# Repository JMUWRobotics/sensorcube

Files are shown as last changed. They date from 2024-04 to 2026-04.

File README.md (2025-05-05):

# Sensor Cube
Documentation, design and example code for the Sensor Cube used for teaching at the Robotics Lab of the Julius Maximilian University of Würzburg.
* The sensors can be used without specialized drivers. The stereo camera behaves like a webcam. The Arduino offers a virtual serial port over USB with sensor messages in JSON format.
* Contact: Michael Bleier (michael.bleier@uni-wuerzburg.de)

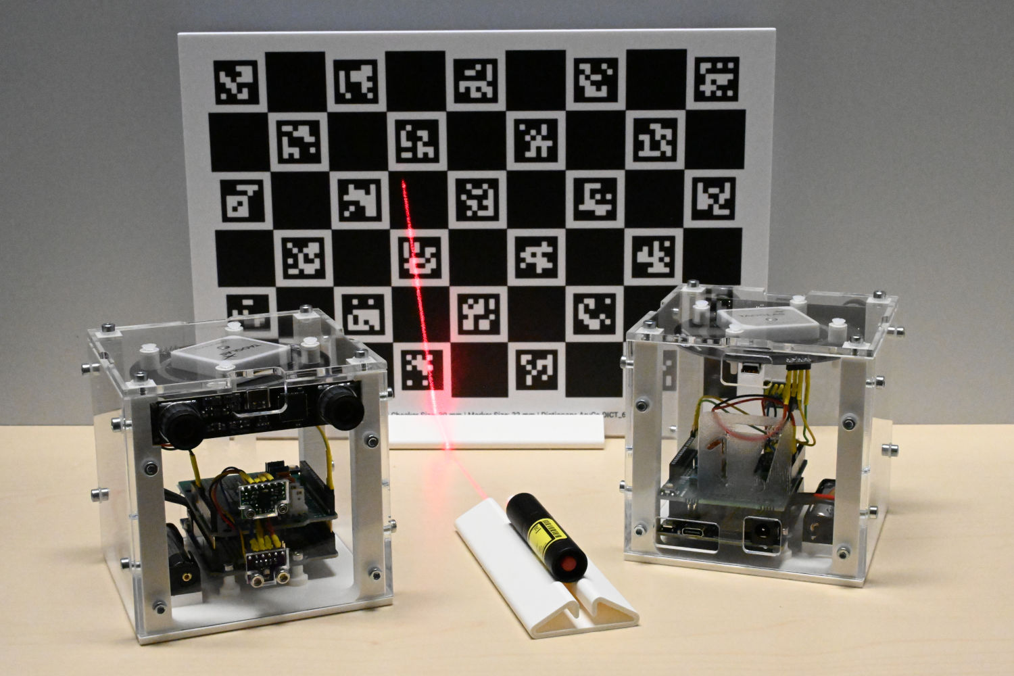
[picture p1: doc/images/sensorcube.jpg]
Image of Sensor Cube Sensor Cube


## Sensors and Kit
* Stereo camera module (https://www.elpcctv.com/elp-4mp-3840x1080p-60fps-synchronous-dual-lens-usb-camera-module-with-no-distortion-85-degree-lens-p-406.html)
* Arduino UNO R4 WiFi
  * U-blox NEO-M8T timing GNSS module (https://www.u-blox.com/en/product/neolea-m8t-series, https://gnss.store/neo-m8t-timing-gnss-modules/53-elt0040.html)
  * ST VL53L3CX Time-of-Flight multi-target distance sensor (https://www.st.com/en/imaging-and-photonics-solutions/vl53l3cx.html, https://www.pololu.com/product/3416)
  * Bosch BMP280 pressure and temperature sensor (https://www.bosch-sensortec.com/products/environmental-sensors/pressure-sensors/bmp280/, https://www.berrybase.de/bmp280-breakout-board-2in1-sensor-fuer-temperatur-und-luftdruck)
  * Bosch BNO055 Inertial Measurement Unit (https://www.bosch-sensortec.com/products/smart-sensor-systems/bno055/, https://docs.arduino.cc/hardware/9-axis-motion-shield/)
* Red Line Laser 650nm (https://www.laserfuchs.de/p/70134933)
* Calibration Board
* Folding Ruler

## Datasheets
* U-blox NEO-M8T timing GNSS module: https://www.u-blox.com/sites/default/files/documents/NEO-LEA-M8T-FW3_DataSheet_UBX-15025193.pdf
* ST VL53L3CX Time-of-Flight multi-target distance sensor: https://www.st.com/resource/en/datasheet/vl53l3cx.pdf
* Bosch BMP280 pressure and temperature sensor: https://www.bosch-sensortec.com/media/boschsensortec/downloads/datasheets/bst-bmp280-ds001.pdf
* Bosch BNO055 Inertial Measurement Unit: https://www.bosch-sensortec.com/media/boschsensortec/downloads/datasheets/bst-bno055-ds000.pdf

## Configuration
In the root directory is a configuration file _"config.json"_. Please make sure to set _"serial\_port"_ (typically _"/dev/ttyACM[0-9]"_ on Linux or _"COM[1-9]"_ on Windows) and the correct _"camera\_index"_ for the stereo camera.

```
"config.json":
  {
    "serial_port" : "/dev/ttyACM0",
    "serial_baudrate" : 921600,
    "camera_index" : 0,
    "camera_width" : 1600,
    "camera_height": 600
  }
```

The Python examples load this file relative to the _*.py_ source files. For the C++ examples CMake sets the path relative to the project source dir and bakes the path in the executables.

## Udev Rules Setup
On GNU/Linux make sure that you have access rights for the serial device (typically _"/dev/ttyACM[0-9]"_) of the Arduino in the Sensor Cube. On Debian/Ubuntu the device will have access rights for the group _plugdev_. Make sure your user is in the group _plugdev_.

Alternatively, the repository includes a udev rule, which grants read and write access to the device for all users:
```
sudo cp udev/99-sensorcube.rules /etc/udev/rules.d/
sudo udevadm control --reload-rules
```

## Using the Sensor Cube with Python
Set up your Python programming environment.

* Install Python3. On GNU/Linux you can use your favorite package manager to install Python, e.g., on Debian/Ubuntu install the package:
  ```
  sudo apt install python3
  ```
* On GNU/Linux use your favorite package manager to install the Python dependencies, e.g., on Debian/Ubuntu install the packages:
  ```
  sudo apt install python3-opencv python3-serial python3-matplotlib python3-numpy
  ```
  Or, use _pip_ to install the dependencies:
  ```
  $ pip install opencv-python pyserial matplotlib numpy
  ```
* Inspect the Python examples in the directory [_examples/python_](examples/python).

## Using the Sensor Cube with C++
Set up your C++ programming environment.

* Set up your C++ programming environment and compiler, e.g., _GCC_ on GNU/Linux or _Visual Studio/MSVC_ on Windows.
* Install the _OpenCV_ library.

  For image processing we will be using the _OpenCV_ library which is available	across platforms. It is recommended to use version 4.5.4. However, any version newer than 4.4.0 should be fine to complete the assignments.

  Please refer to: https://docs.opencv.org/4.5.4/df/d65/tutorial_table_of_content_introduction.html

  GNU/Linux: Use your favorite package manager to install OpenCV, e.g., on Debian/Ubuntu install the package:
  ```
  sudo apt install libopencv-dev
  ```
  Windows: You can download the _OpenCV_ binary release from https://opencv.org/releases/. You need to add the path to the unpacked directory _"opencv/build/x64/vc16/bin"_ to your System Path, such that the _OpenCV_ DLLs are found.
  
  Of course it is also possible to compile OpenCV yourself or use other ways for the installation as listed in the _OpenCV_ documentation.
* Install the _CMake_ build system.

  GNU/Linux: Use your favorite package manager to install _CMake_, e.g., on Debian/Ubuntu install the package:
  ```
  sudo apt install cmake
  ```
  Windows: You can download _CMake_ from https://cmake.org/download/.
  
* All other library dependencies (_Eigen3_, _Nlohmann JSON_, and _Asio_) are automatically downloaded by _CMake_. Inspect the _"examples/cpp/CMakeLists.txt"_ project file.
* Build the C++ examples. The recommended way of building a project with _CMake_ is by doing an out-of-source build. This can be done like this:
  ```
  $ cd examples/cpp
  $ mkdir build && cd build
  $ cmake ..
  $ make
  ```
  If _OpenCV_ is not installed in the standard paths, you might need to set the _OpenCV_ directory:
  ```
  $ cmake -DOpenCV_DIR=<Path to directory OpenCVConfig.cmake> ..
  ```
  If you are using the _OpenCV_ binary release on Windows, you need to specify the path to the unpacked directory _"opencv/build/x64/vc16/lib"_.

  Different _CMake_ Generators are available, such as _Unix Makefiles_ or _Ninja_. On Windows CMake can create, for example, _Visual Studio_ project files, _NMake_, or _Unix Makefiles_: https://cmake.org/cmake/help/latest/manual/cmake-generators.7.html
	
  For example, on Windows you can run from the Visual Studio developer command prompt:
  ```
  $ cmake -G "NMake Makefiles" ..
  $ nmake
  ```
* Inspect the C++ examples in the directory [_examples/cpp/src_](examples/cpp/src).

## Tools
* Record messages:
  ```
  python3 recordMessages.py -m <message_type> -f <file_name>
  ```
  Example record _imu_raw_ data to file _imu_raw.json_:
  ```
  python3 recordMessages.py -m imu_raw -f imu_raw.json
  ```
* Print messages:
  Without the file option _-f_ you can also use the record tool to print the messages.
  ```
  python3 recordMessages.py -m <message_type>
  ```
* Plot raw IMU data:
  ```
  python3 showIMU.py
  ```
* Capture Images:
  ```
  python3 captureCamera.py
  ```
  Press spacebar to capture images and ESC to quit.

* Update Real Time Clock:
  ```
  python3 setTime.py
  ```
## Known Issues
* The Arduino UNO R4 WiFi uses the internal oscillator instead of an external crystal as a clock source for the Real Time Clock (RTC). This causes significant time drift.
* The stereo camera can be slow with _OpenCV_ Video Capture. Therefore, the default configuration uses a stereo image size of only 1600 x 600.
* OpenCV changed the physical layout (the order of the 2D barcodes) of ChArUco boards in OpenCV 4.6.0. A fix was added in OpenCV 4.8.0 ("board.setLegacyPattern(True)"). Therefore, the ChArUco boards in the Sensor Cube boxes cannot be detected with OpenCV versions >= 4.6.0 and < 4.8.0.\
GitHub issue: https://github.com/opencv/opencv/issues/23152

## Publication
The following publication talks about some of the design aspects and application of the Sensor Cube for teaching: https://doi.org/10.1016/j.ifacol.2024.08.456
```
Bleier, M. (2024). Sensor Cube – A Tool for Hands-on Learning of Sensor Data Processing. IFAC-PapersOnLine, 58(16), 23-28.
```

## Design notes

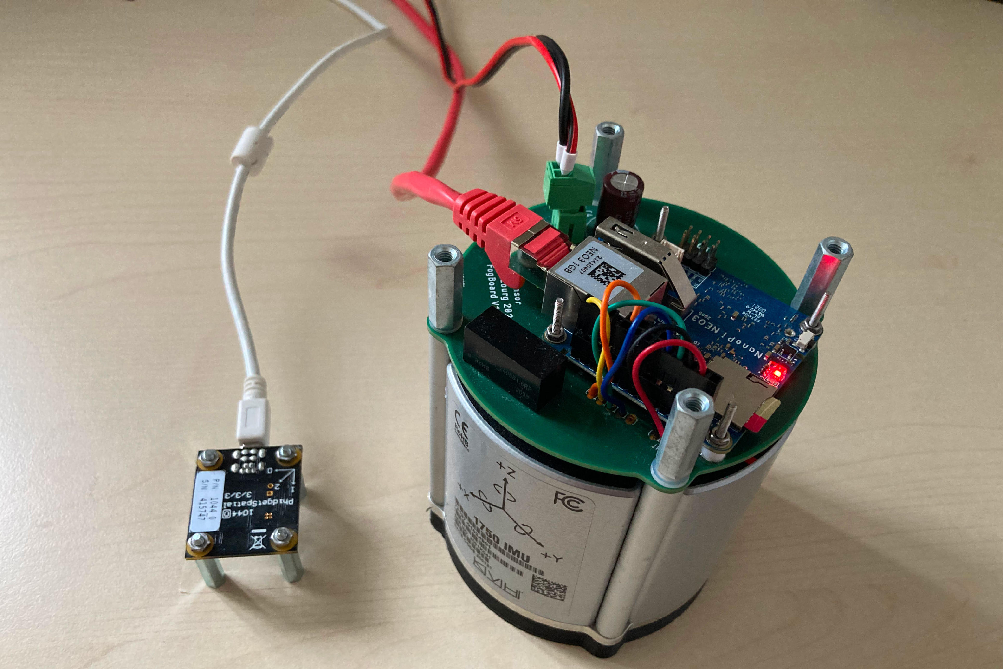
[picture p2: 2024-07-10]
doc/images/phidgets_spatial_kvh_fog.jpg

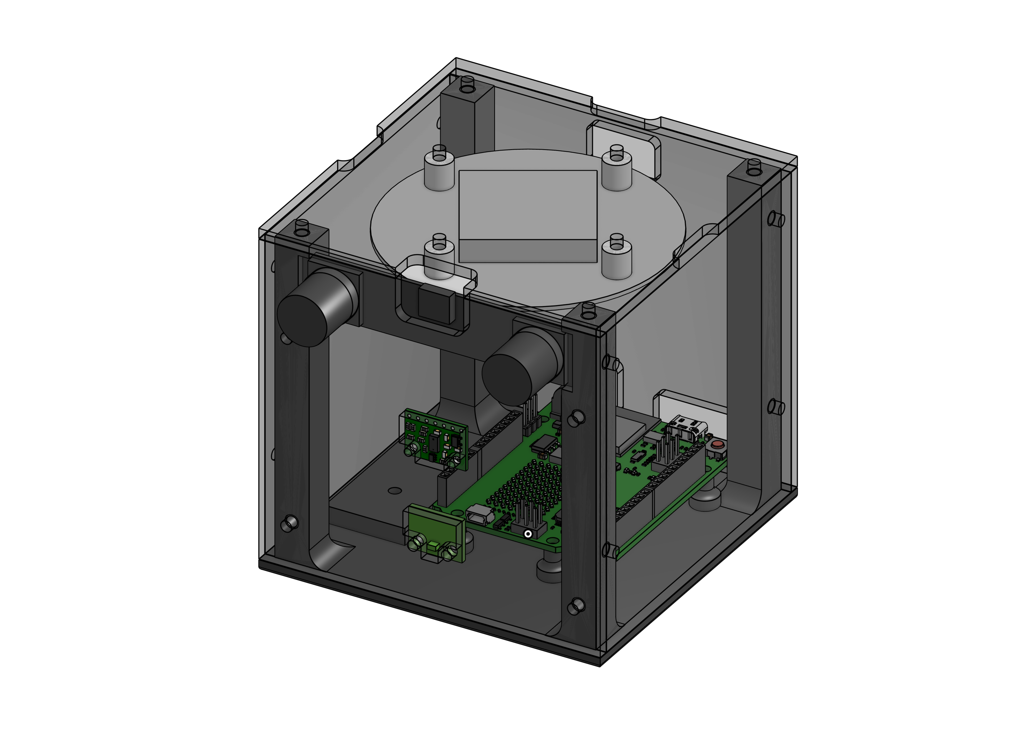
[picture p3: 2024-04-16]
cad/Cube002.png

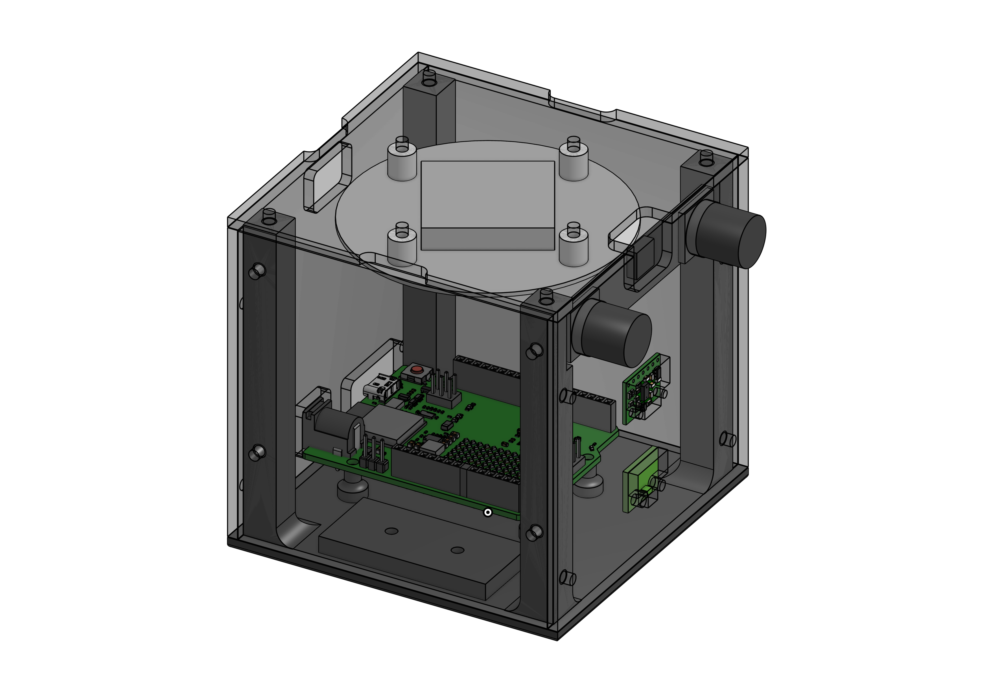
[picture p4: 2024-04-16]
cad/Cube001.png

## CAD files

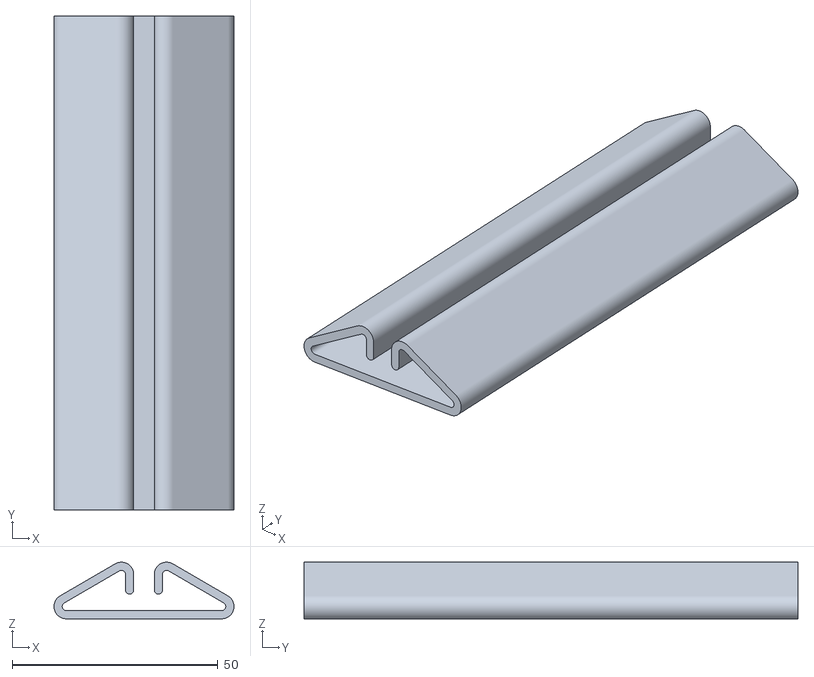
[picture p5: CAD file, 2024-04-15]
cad/3dprint/BoardStand.stl
43.8 x 120.0 x 13.8

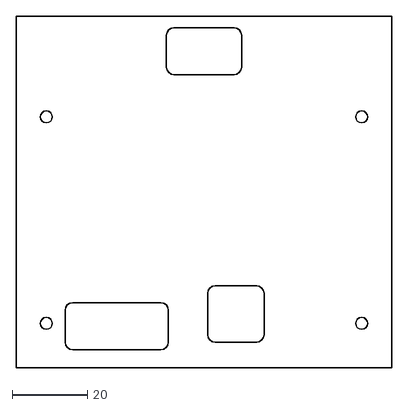
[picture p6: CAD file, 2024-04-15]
cad/lasercut/Front.dxf
100.0 x 93.6

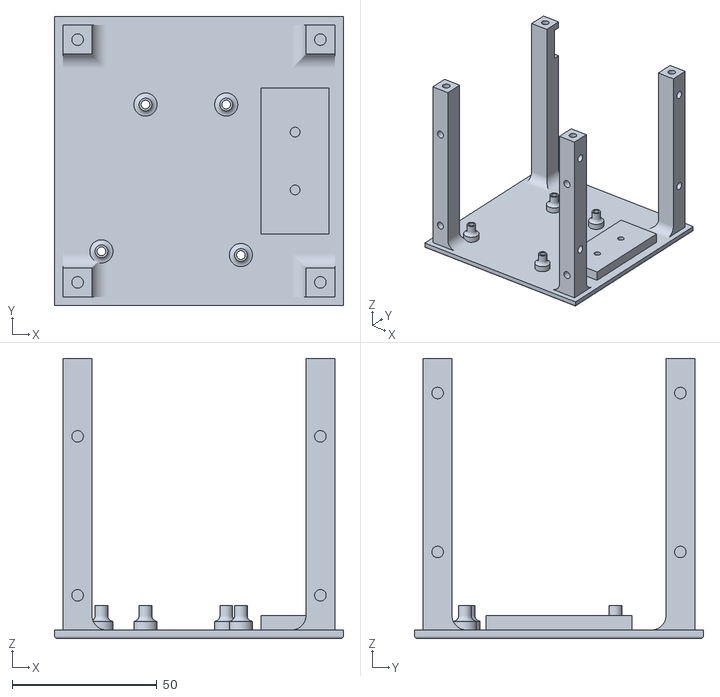
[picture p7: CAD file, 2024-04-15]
cad/3dprint/CubeStructure.stl
100.0 x 100.0 x 97.0

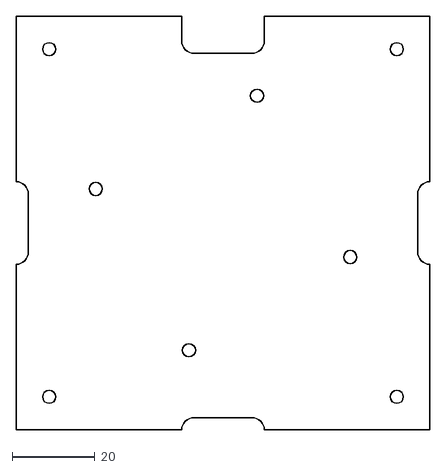
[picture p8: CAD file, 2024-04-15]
cad/lasercut/Top.dxf
100.0 x 100.0

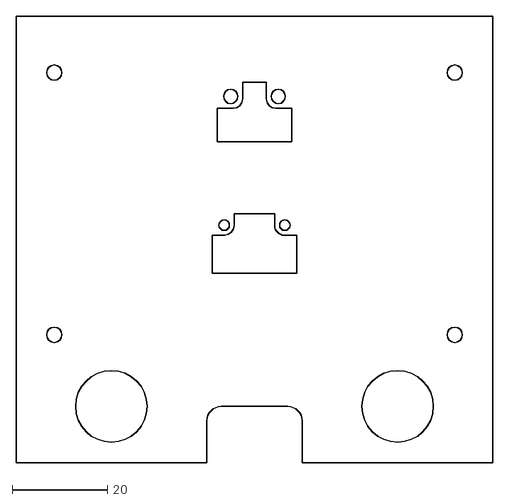
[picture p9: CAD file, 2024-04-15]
cad/lasercut/Back.dxf
100.0 x 93.6

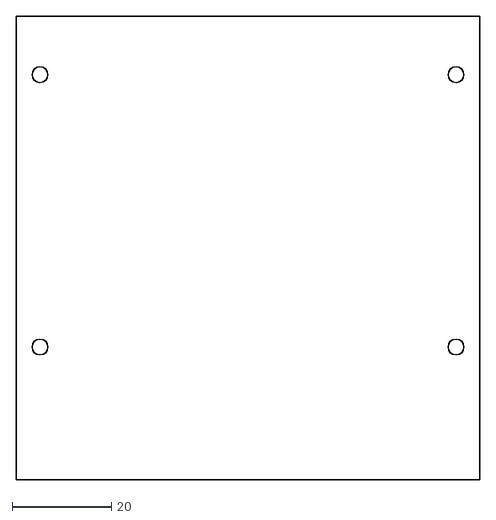
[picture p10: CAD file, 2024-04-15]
cad/lasercut/Left.dxf
93.6 x 93.6

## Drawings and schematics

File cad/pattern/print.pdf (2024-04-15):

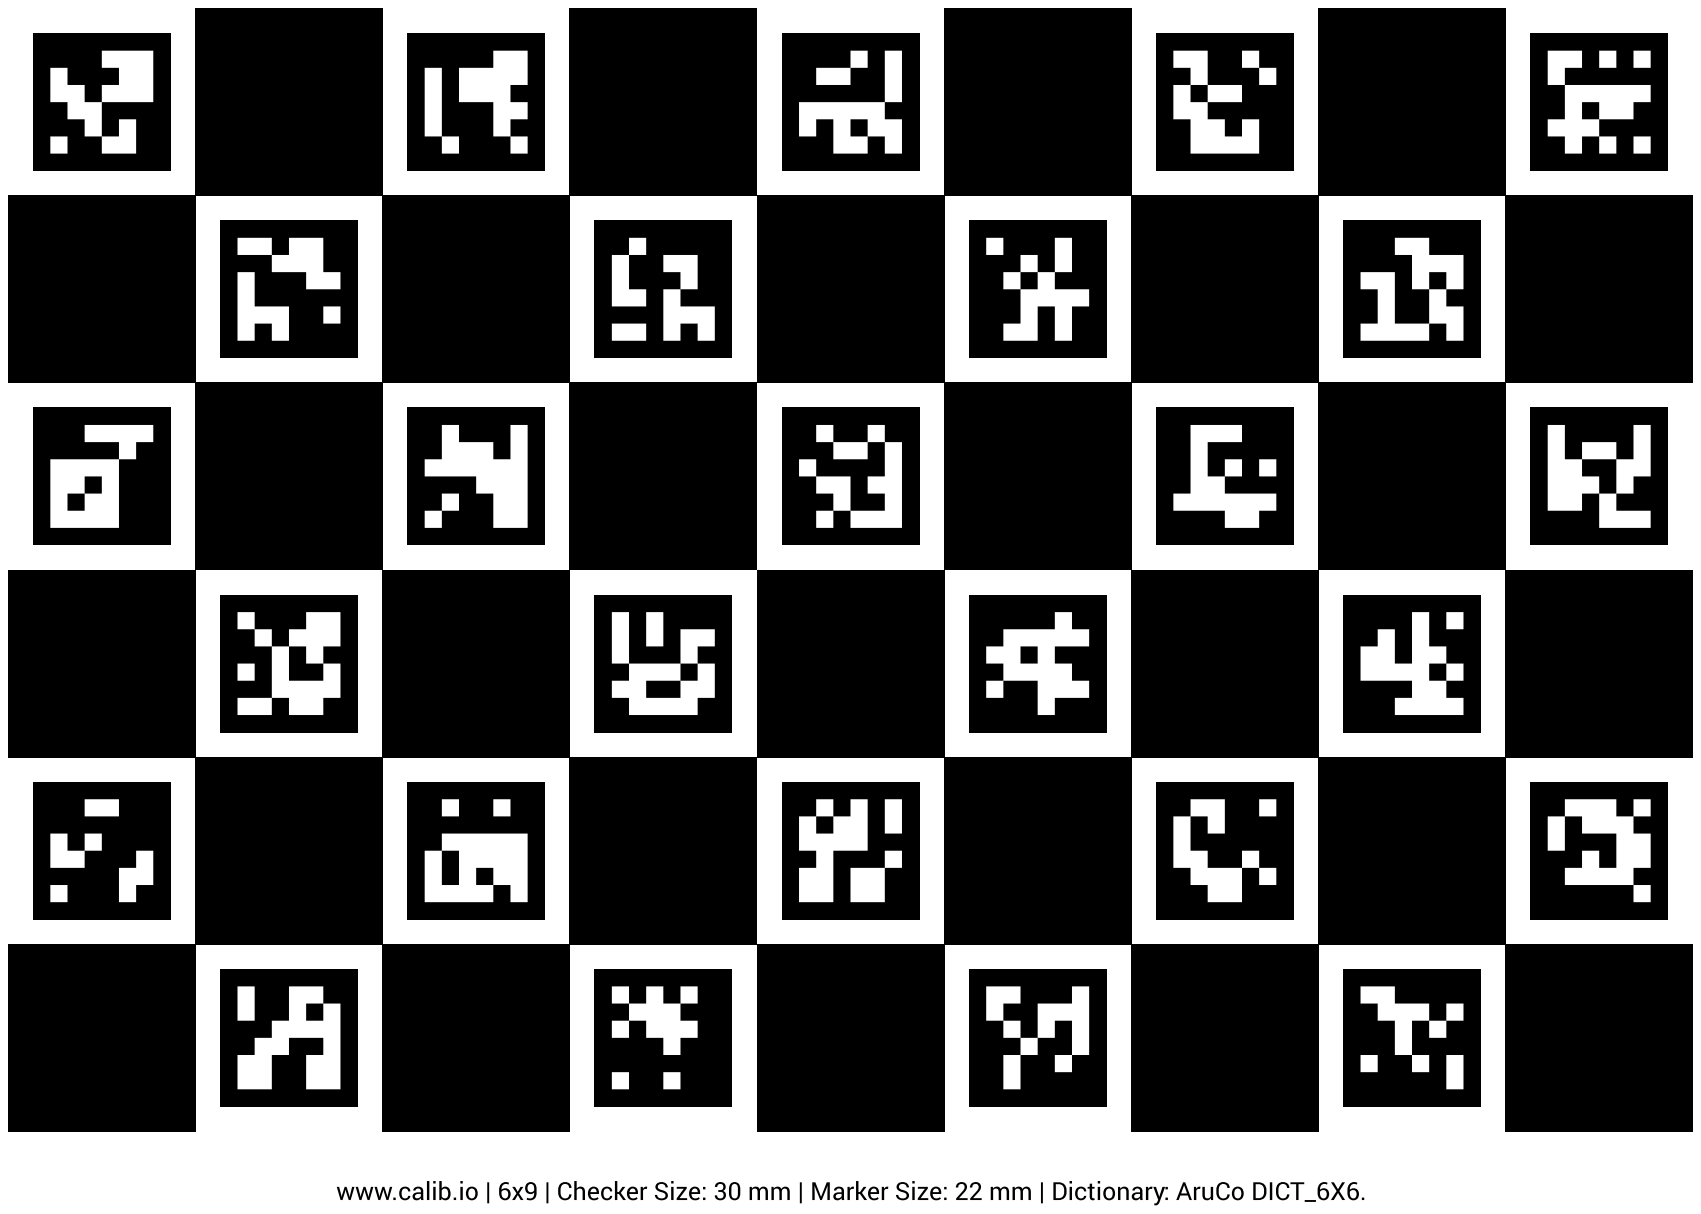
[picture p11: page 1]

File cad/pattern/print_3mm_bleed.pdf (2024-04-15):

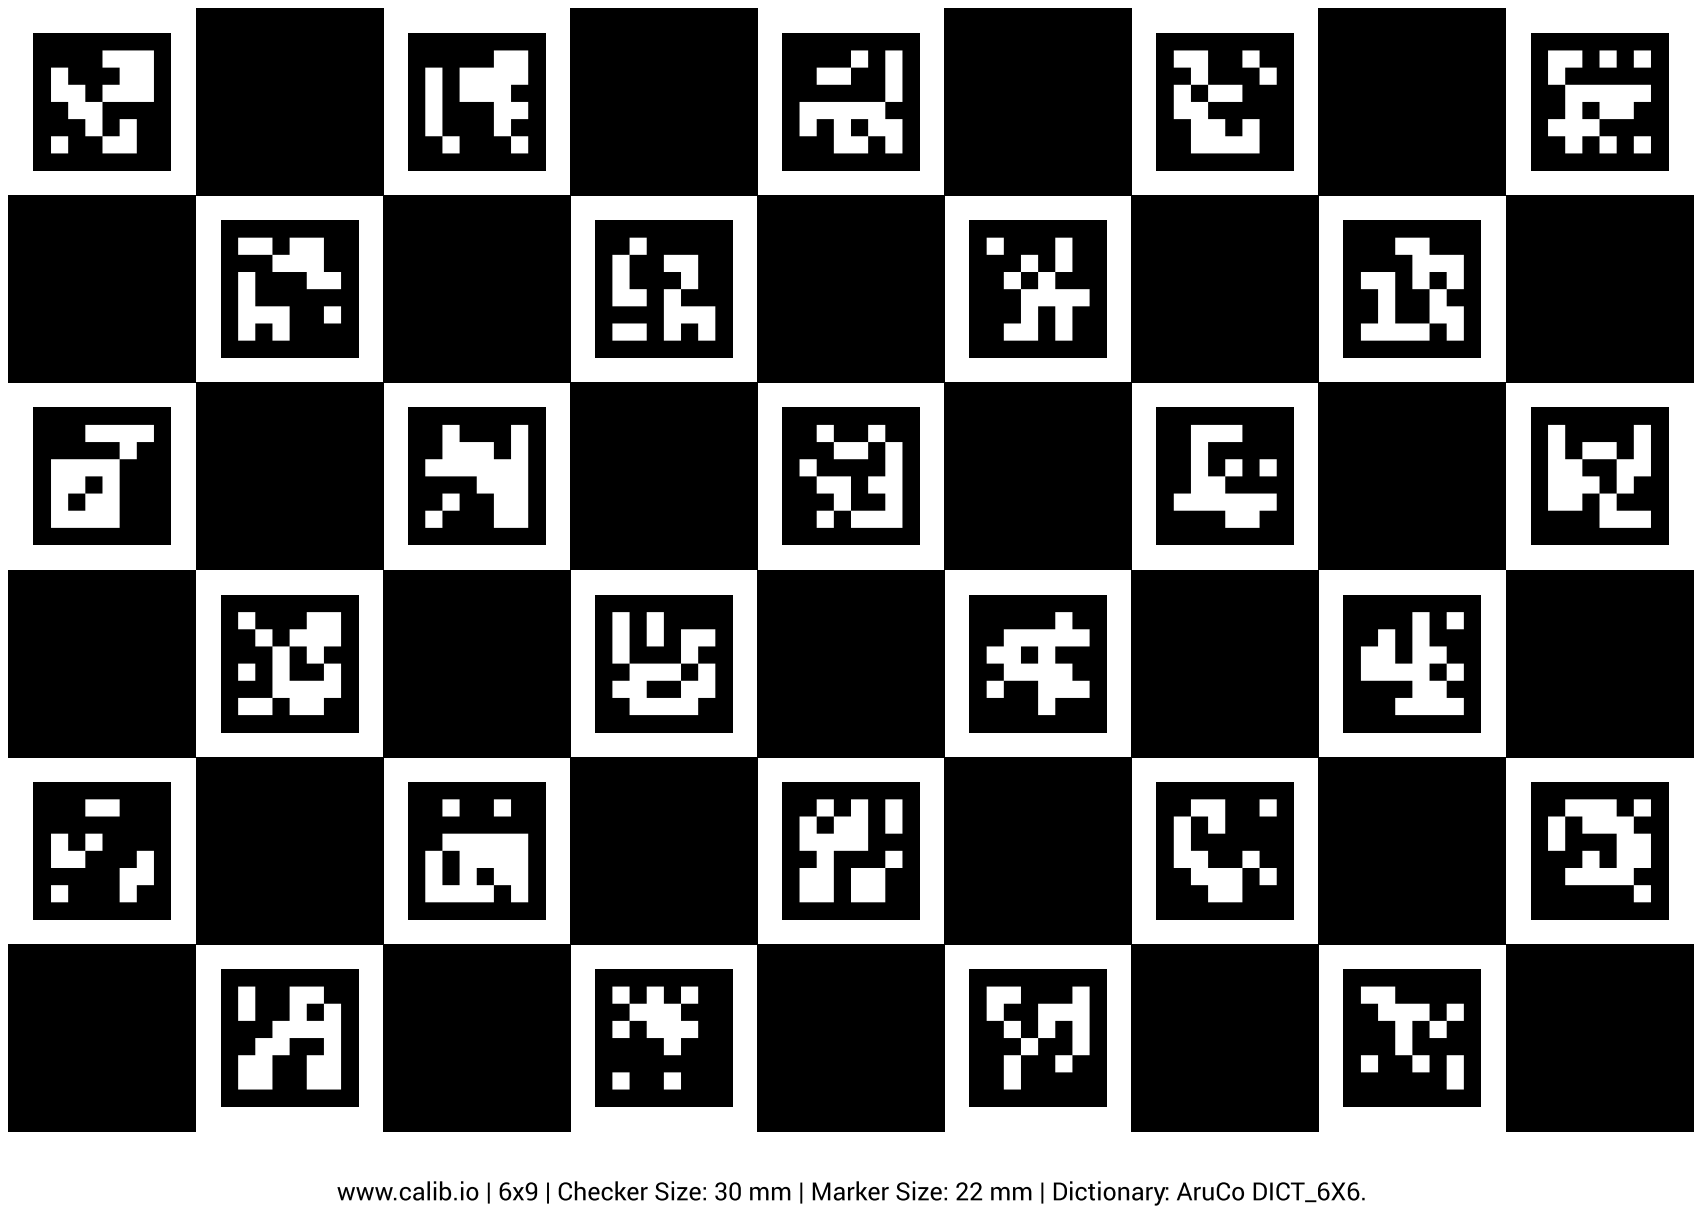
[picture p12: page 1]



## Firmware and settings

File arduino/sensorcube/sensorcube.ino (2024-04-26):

#include <ArduinoJson.h>
#include "RTC.h"
#include <Wire.h>
#include "Arduino_NineAxesMotion.h"
#include <vl53lx_class.h>
#include "DFRobot_BMP280.h"

struct MessageSelection
{
  bool heartbeat = true;
  bool imu_raw = false;
  bool imu_linear = false;
  bool imu_euler = false;
  bool imu_quaternion = false;
  bool tof_raw = false;
  bool pressure_raw = false;
  bool gnss_raw = false;
} messageSelection;

const size_t MAX_DATA_LENGTH = 400;
char buffer[MAX_DATA_LENGTH + 1];

unsigned long seqText = 0;

RTCTime startTime;
StaticJsonDocument<400> doc;
NineAxesMotion imu;
VL53LX tof(&Wire1, A1);
DFRobot_BMP280_IIC bmp(&Wire1, DFRobot_BMP280_IIC::eSdoLow);

void heartbeat()
{
  static unsigned long lastTime = millis();
  static unsigned long seq = 0;

  if (messageSelection.heartbeat && (millis() - lastTime) >= 1000) {  
    lastTime = millis();

    RTCTime currentTime;
    RTC.getTime(currentTime);

    doc.clear();
    doc["msg"] = "heartbeat";
    doc["stamp"] = serialized(String(startTime.getUnixTime() + millis() / 1000.0, 3));
    doc["seq"] = seq++;
    serializeJson(doc, Serial);
    Serial.println();
  }
}

void imu_raw()
{
  static unsigned long lastTime = millis();
  static unsigned long seq = 0;

  if (messageSelection.imu_raw && (millis() - lastTime) >= 10) {
    lastTime = millis();

    RTCTime currentTime;
    RTC.getTime(currentTime);
    imu.updateAccel();
    imu.updateGyro();
    imu.updateMag();

    doc.clear();
    doc["msg"] = "imu_raw";
    doc["stamp"] = serialized(String(startTime.getUnixTime() + millis() / 1000.0, 3));
    doc["seq"] = seq++;
    doc["ax"] = imu.readAccelX();
    doc["ay"] = imu.readAccelY();
    doc["az"] = imu.readAccelZ();
    doc["wx"] = imu.readGyroX();
    doc["wy"] = imu.readGyroY();
    doc["wz"] = imu.readGyroZ();
    doc["mx"] = imu.readMagX();
    doc["my"] = imu.readMagY();
    doc["mz"] = imu.readMagZ();
    serializeJson(doc, Serial);
    Serial.println();
  }
}

void imu_linear()
{
  static unsigned long lastTime = millis();
  static unsigned long seq = 0;

  if (messageSelection.imu_linear && (millis() - lastTime) >= 10) {
    lastTime = millis();

    RTCTime currentTime;
    RTC.getTime(currentTime);
    imu.updateLinearAccel();
    imu.updateGyro();
    imu.updateMag();

    doc.clear();
    doc["msg"] = "imu_linear";
    doc["stamp"] = serialized(String(startTime.getUnixTime() + millis() / 1000.0, 3));
    doc["seq"] = seq++;
    doc["lx"] = imu.readLinearAccelX();
    doc["ly"] = imu.readLinearAccelY();
    doc["lz"] = imu.readLinearAccelZ();
    doc["wx"] = imu.readGyroX();
    doc["wy"] = imu.readGyroY();
    doc["wz"] = imu.readGyroZ();
    doc["mx"] = imu.readMagX();
    doc["my"] = imu.readMagY();
    doc["mz"] = imu.readMagZ();
    serializeJson(doc, Serial);
    Serial.println();
  }
}

void imu_euler()
{
  static unsigned long lastTime = millis();
  static unsigned long seq = 0;

  if (messageSelection.imu_euler && (millis() - lastTime) >= 10) {
    lastTime = millis();

    RTCTime currentTime;
    RTC.getTime(currentTime);
    imu.updateEuler();

    doc.clear();
    doc["msg"] = "imu_euler";
    doc["stamp"] = serialized(String(startTime.getUnixTime() + millis() / 1000.0, 3));
    doc["seq"] = seq++;
    doc["heading"] = imu.readEulerHeading();
    doc["roll"] = imu.readEulerRoll();
    doc["pitch"] = imu.readEulerPitch();
    serializeJson(doc, Serial);
    Serial.println();
  }
}

void imu_quaternion()
{
  static unsigned long lastTime = millis();
  static unsigned long seq = 0;

  if (messageSelection.imu_quaternion && (millis() - lastTime) >= 10) {
    lastTime = millis();

    RTCTime currentTime;
    RTC.getTime(currentTime);
    imu.updateQuat();

    doc.clear();
    doc["msg"] = "imu_quaternion";
    doc["stamp"] = serialized(String(startTime.getUnixTime() + millis() / 1000.0, 3));
    doc["seq"] = seq++;
    doc["qx"] = imu.readQuatX() / 1000.0;
    doc["qy"] = imu.readQuatY() / 1000.0;
    doc["qz"] = imu.readQuatZ() / 1000.0;
    doc["qw"] = imu.readQuatW() / 1000.0;
    serializeJson(doc, Serial);
    Serial.println();
  }
}

void tof_raw()
{
  static unsigned long lastTime = millis();
  static unsigned long seq = 0;
  int status = 0;

  if (messageSelection.tof_raw && (millis() - lastTime) >= 1) {
    lastTime = millis();

    uint8_t NewDataReady = 0;
    status = tof.VL53LX_GetMeasurementDataReady(&NewDataReady);

    if ((!status) && (NewDataReady != 0)) {
      RTCTime currentTime;
      RTC.getTime(currentTime);

      VL53LX_MultiRangingData_t multiRangingData;

      status = tof.VL53LX_GetMultiRangingData(&multiRangingData);
      int numberOfObjects = multiRangingData.NumberOfObjectsFound;

      doc.clear();
      doc["msg"] = "tof_raw";
      doc["stamp"] = serialized(String(startTime.getUnixTime() + millis() / 1000.0, 3));
      doc["seq"] = seq++;
      doc["objects"] = numberOfObjects;
      JsonArray range = doc.createNestedArray("range");
      for (int i = 0; i < numberOfObjects; i++) {
        range.add(multiRangingData.RangeData[i].RangeMilliMeter / 1000.0);
      }
      JsonArray signal = doc.createNestedArray("signal");
      for (int i = 0; i < numberOfObjects; i++) {
        signal.add(multiRangingData.RangeData[i].SignalRateRtnMegaCps / 65536.0);
      }
      serializeJson(doc, Serial);
      Serial.println();

      if (status == 0) {
        status = tof.VL53LX_ClearInterruptAndStartMeasurement();
      }
    }
  }
}

void pressure_raw()
{
  static unsigned long lastTime = millis();
  static unsigned long seq = 0;

  if (messageSelection.pressure_raw && (millis() - lastTime) >= 1000) {
    lastTime = millis();

    RTCTime currentTime;
    RTC.getTime(currentTime);
    float temperature = bmp.getTemperature();
    uint32_t pressure = bmp.getPressure();

    doc.clear();
    doc["msg"] = "pressure_raw";
    doc["stamp"] = serialized(String(startTime.getUnixTime() + millis() / 1000.0, 3));
    doc["seq"] = seq++;
    doc["temperature"] = serialized(String(temperature,2));
    doc["pressure"] = pressure;
    serializeJson(doc, Serial);
    Serial.println();
  }
}

void gnss_raw()
{
  if (messageSelection.gnss_raw && Serial1.available()) {
    Serial.write(Serial1.read());
  }
}

bool add_data(char nextChar)
{  
  static uint8_t currentIndex = 0;

  if (nextChar == '\n') {
      buffer[currentIndex] = '\0';
      currentIndex = 0;
      return true;
  }

  buffer[currentIndex] = nextChar;
  currentIndex++;

  if (currentIndex >= MAX_DATA_LENGTH) {
    buffer[MAX_DATA_LENGTH] = '\0';
    currentIndex = 0;
    return true;
  }

  return false;
}

void process_command()
{
  StaticJsonDocument<400> docCommand;
  DeserializationError error = deserializeJson(docCommand, buffer);

  if (error) {
    RTCTime currentTime;
    RTC.getTime(currentTime);
    doc.clear();
    doc["msg"] = "text";
    doc["stamp"] = serialized(String(startTime.getUnixTime() + millis() / 1000.0, 3));
    doc["seq"] = seqText++;
    doc["text"] = "Failed to deserialize command!";
    serializeJson(doc, Serial);
    Serial.println();
    
    return;
  }

  if (docCommand.containsKey("messages")) {
    messageSelection.heartbeat = false;
    messageSelection.imu_raw = false;
    messageSelection.imu_linear = false;
    messageSelection.imu_euler = false;
    messageSelection.imu_quaternion = false;
    messageSelection.tof_raw = false;
    messageSelection.pressure_raw = false;
    messageSelection.gnss_raw = false;

    JsonArray array = docCommand["messages"].as<JsonArray>();
    for (JsonVariant v : array) {
      std::string s = v.as<std::string>();

      if (s.compare("heartbeat") == 0) { messageSelection.heartbeat = true; }
      if (s.compare("imu_raw") == 0) { messageSelection.imu_raw = true; }
      if (s.compare("imu_linear") == 0) { messageSelection.imu_linear = true; }
      if (s.compare("imu_euler") == 0) { messageSelection.imu_euler = true; }
      if (s.compare("imu_quaternion") == 0) { messageSelection.imu_quaternion = true; }
      if (s.compare("tof_raw") == 0) { messageSelection.tof_raw = true; }
      if (s.compare("pressure_raw") == 0) { messageSelection.pressure_raw = true; }
      if (s.compare("gnss_raw") == 0) { messageSelection.gnss_raw = true; }
    }
  }

  if (docCommand.containsKey("time")) {
    RTCTime newTime;
    newTime.setUnixTime(docCommand["time"].as<unsigned long>());
    RTC.setTime(newTime);
    startTime.setUnixTime(docCommand["time"].as<unsigned long>() - (millis() / 1000ul));

    RTCTime currentTime;
    RTC.getTime(currentTime);
    doc.clear();
    doc["msg"] = "text";
    doc["stamp"] = serialized(String(startTime.getUnixTime() + millis() / 1000.0, 3));
    doc["seq"] = seqText++;
    doc["text"] = "Updated RTC!";
    serializeJson(doc, Serial);
    Serial.println();
  }
}

void process_serial()
{
  bool dataReady = false;

  while (Serial.available() > 0) {
      char data = Serial.read();
      dataReady = add_data(data);
      if (dataReady) {
        process_command();
      }
  }
}

void setup()
{
  RTC.begin();
  RTC.getTime(startTime);
  RTC.setTime(startTime);

  Serial.begin(921600);

  Wire.begin();
  Wire.setClock(I2C_MASTER_RATE_FAST);
  imu.initSensor();
  imu.setOperationMode(OPERATION_MODE_NDOF);
  imu.setUpdateMode(MANUAL);

  Wire1.begin();
  tof.begin();
  tof.VL53LX_Off();
  tof.InitSensor(0x12);
  tof.VL53LX_StartMeasurement();
  
  bmp.reset();
  while(bmp.begin() != DFRobot_BMP280_IIC::eStatusOK) {
    RTCTime currentTime;
    RTC.getTime(currentTime);
    doc.clear();
    doc["msg"] = "text";
    doc["stamp"] = serialized(String(startTime.getUnixTime() + millis() / 1000.0, 3));
    doc["seq"] = seqText++;
    doc["text"] = "BMP280 begin failed!";
    serializeJson(doc, Serial);
    Serial.println();

    delay(1000);
  }

  Serial1.begin(921600);

  // start aligned with full seconds
  while (millis() % 1000 != 0) {}
}

void loop()
{
  heartbeat();
  imu_raw();
  imu_linear();
  imu_euler();
  imu_quaternion();
  tof_raw();
  pressure_raw();
  gnss_raw();

  process_serial();
}

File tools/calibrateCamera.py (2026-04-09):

import numpy as np
import cv2
from cv2 import aruco
import argparse
import glob
import os.path
import click
import sys

(major, minor, _) = cv2.__version__.split(".")

if not (int(major) >= 4 and int(minor) >= 8):
    print("OpenCV " + str(cv2.__version__) + " detected.")
    print("This Python program requires OpenCV >= 4.8.0.")
    sys.exit(1)

parser = argparse.ArgumentParser(description='Compute camera calibration.')
parser.add_argument(dest='folder', type=str, help='Folder with stereo***.png images.')
args = parser.parse_args()

CHARUCOBOARD_ROWCOUNT = 6
CHARUCOBOARD_COLCOUNT = 9
CHARUCOBOARD_SQUARE_LENGTH = 0.030
CHARUCOBOARD_MARKER_SIZE = 0.022

dictionary = cv2.aruco.getPredefinedDictionary(aruco.DICT_6X6_1000)
board = cv2.aruco.CharucoBoard((CHARUCOBOARD_COLCOUNT, CHARUCOBOARD_ROWCOUNT), CHARUCOBOARD_SQUARE_LENGTH, CHARUCOBOARD_MARKER_SIZE, dictionary)
board.setLegacyPattern(True)
detctorparams = cv2.aruco.DetectorParameters()
charucoparams = cv2.aruco.CharucoParameters()
charucoparams.tryRefineMarkers = True
detector = cv2.aruco.CharucoDetector(board, charucoparams, detctorparams)

images = glob.glob(args.folder + '/stereo*.png')

if len(images) < 3:
    print("Calibration was unsuccessful. Too few images were found.")
    exit()

image_size_left = None
corners_all_left = []
ids_all_left = []
image_left = []

image_size_right = None
corners_all_right = []
ids_all_right = []
image_right = []

for iname in images:
    print(iname)
    img = cv2.imread(iname)
    gray = cv2.cvtColor(img, cv2.COLOR_BGR2GRAY)

    left = img[0:img.shape[0], 0:int(img.shape[1]/2)]
    leftGray = cv2.cvtColor(left, cv2.COLOR_BGR2GRAY)
    if len(image_left) < 1:
        image_left = left.copy()

    charuco_corners, charuco_ids, corners, ids = detector.detectBoard(leftGray)

    left = aruco.drawDetectedMarkers(
        image=left, 
        corners=corners)
    if len(charuco_ids) > 1:
        corners_all_left.append(charuco_corners)
        ids_all_left.append(charuco_ids)
        
        left = aruco.drawDetectedCornersCharuco(
            image=left,
            charucoCorners=charuco_corners,
            charucoIds=charuco_ids)

    if not image_size_left:
        image_size_left = leftGray.shape[::-1]

    right = img[0:img.shape[0], int(img.shape[1]/2):img.shape[1]]
    rightGray = cv2.cvtColor(right, cv2.COLOR_BGR2GRAY)
    if len(image_right) < 1:
        image_right = right.copy()

    charuco_corners, charuco_ids, corners, ids = detector.detectBoard(rightGray)

    right = aruco.drawDetectedMarkers(
        image=right, 
        corners=corners)
    if len(charuco_ids) > 1:
        corners_all_right.append(charuco_corners)
        ids_all_right.append(charuco_ids)
        
        right = aruco.drawDetectedCornersCharuco(
            image=right,
            charucoCorners=charuco_corners,
            charucoIds=charuco_ids)

    if not image_size_right:
        image_size_right = rightGray.shape[::-1]

    displayImg = cv2.hconcat([left, right])
    proportion = max(displayImg.shape) / 1000.0
    displayImg = cv2.resize(displayImg,
        (int(displayImg.shape[1]/proportion), int(displayImg.shape[0]/proportion)))

    cv2.imshow('Detected ChArUco markers', displayImg)
    cv2.waitKey(100)

cv2.destroyAllWindows()

fs = None
if os.path.isfile("calibration.json"):
    if click.confirm('\nFile calibration.json exists. Overwrite?', default=True):
        fs = cv2.FileStorage("calibration.json", cv2.FILE_STORAGE_WRITE)
else:
    fs = cv2.FileStorage("calibration.json", cv2.FILE_STORAGE_WRITE)

ret, camera_matrix_left, dist_coeffs_left, rvecs, tvecs = aruco.calibrateCameraCharuco(
    charucoCorners=corners_all_left,
    charucoIds=ids_all_left,
    board=board,
    imageSize=image_size_left,
    cameraMatrix=None,
    distCoeffs=None)

print("\nLeft camera:")
print(f"Error: {ret}")
print("Camera matrix:")
print(camera_matrix_left)
print("Distortion coefficients:")
print(dist_coeffs_left)

new_camera_matrix_left, roi = cv2.getOptimalNewCameraMatrix(camera_matrix_left, dist_coeffs_left, image_size_left, 1, image_size_left)
undistorted_image_left = cv2.undistort(image_left, camera_matrix_left, dist_coeffs_left, None, new_camera_matrix_left)

if fs:
    fs.startWriteStruct('left', cv2.FileNode_MAP)
    fs.write(name='image_size',val=image_size_left)
    fs.write(name='camera_matrix',val=camera_matrix_left)
    fs.write(name='distortion_coefficients',val=dist_coeffs_left)
    fs.endWriteStruct()

ret, camera_matrix_right, dist_coeffs_right, rvecs, tvecs = aruco.calibrateCameraCharuco(
    charucoCorners=corners_all_right,
    charucoIds=ids_all_right,
    board=board,
    imageSize=image_size_right,
    cameraMatrix=None,
    distCoeffs=None)

print("\nRight camera:")
print(f"Error: {ret}")
print("Camera matrix:")
print(camera_matrix_right)
print("Distortion coefficients:")
print(dist_coeffs_right)

new_camera_matrix_right, roi = cv2.getOptimalNewCameraMatrix(camera_matrix_right, dist_coeffs_right, image_size_right, 1, image_size_right)
undistorted_image_right = cv2.undistort(image_right, camera_matrix_right, dist_coeffs_right, None, new_camera_matrix_right)

if fs:
    fs.startWriteStruct('right', cv2.FileNode_MAP)
    fs.write(name='image_size',val=image_size_right)
    fs.write(name='camera_matrix',val=camera_matrix_right)
    fs.write(name='distortion_coefficients',val=dist_coeffs_right)
    fs.endWriteStruct()

displayImg = cv2.vconcat([cv2.hconcat([image_left, image_right]), cv2.hconcat([undistorted_image_left, undistorted_image_right])])
proportion = max(displayImg.shape) / 1000.0
displayImg = cv2.resize(displayImg, (int(displayImg.shape[1]/proportion), int(displayImg.shape[0]/proportion)))


cv2.imshow('Original and undistorted image', displayImg)

obj_all = [];
pts_all_left = [];
pts_all_right = [];
for i in range(len(ids_all_left)):
    ids_left = ids_all_left[i]
    ids_right = ids_all_right[i]
    
    obj = None;
    pts_left = [];
    pts_right = [];
    
    for j in range(len(ids_left)):
        for k in range(len(ids_right)):
            if ids_right[k] == ids_left[j]:
                if obj is None:
                    obj = board.getChessboardCorners()[ids_left[j][0]]
                    pts_left = corners_all_left[i][j]
                    pts_right = corners_all_right[i][k]
                else:
                    obj = np.vstack((obj, board.getChessboardCorners()[ids_left[j][0]]))
                    pts_left = np.vstack((pts_left, corners_all_left[i][j]))
                    pts_right = np.vstack((pts_right, corners_all_right[i][k]))
    if len(obj) > 4:
        obj_all.append(obj)
        pts_all_left.append(pts_left)
        pts_all_right.append(pts_right)

ret, K1, D1, K2, D2, R, T, E, F = cv2.stereoCalibrate(
    obj_all,
    pts_all_left,
    pts_all_right,
    camera_matrix_left, dist_coeffs_left, camera_matrix_right, dist_coeffs_right,
    image_size_left)
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

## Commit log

2024-04-15 Added manufacturing files.
    [Back.dxf, BoardStand.stl, CubeStructure.stl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]
2024-04-15 Added calibration pattern.
2024-04-16 Added cad.
2024-04-16 Added Arduino code.
2024-04-17 Added camera example.
2024-04-17 Added IMU plot tool.
2024-04-20 Added imu_data.
2024-06-26 Added camera calibration tool.
2024-07-04 Fixed calibrateCamera for OpenCV >= 4.7.0.
    [calibrateCamera.py]
2026-04-09 Exit camera calibration on closing all windows.
2026-04-09 Exit camera capture on window close.
